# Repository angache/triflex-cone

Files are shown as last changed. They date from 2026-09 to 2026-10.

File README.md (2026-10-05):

# TriFlex

**Triple-Helix Mesh Trigger Cone**

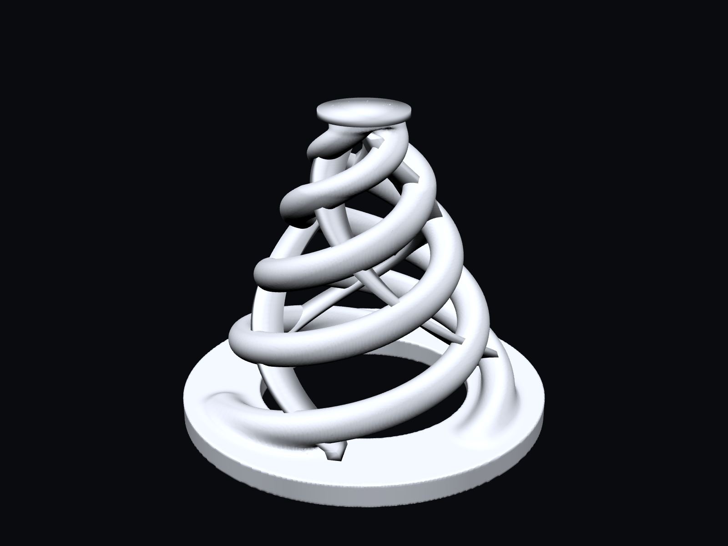
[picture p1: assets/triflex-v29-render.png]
TriFlex V29 render


**TriFlex — A 3D-printable triple-helix piezo trigger cone for electronic mesh drum pads.**

TriFlex is a mechanical trigger-cone project for electronic drums using mesh heads and piezo sensors. Instead of a conventional solid foam cone, it uses three TPU helical spring arms and stabilizing membranes to tune compliance, lateral stability, sensitivity, and hotspot behavior.

## Mechanical concept

The helix arms provide vertical compliance. The membranes add lateral stability and tune the spring response without turning the geometry into a closed shell.

The piezo is approximately 27-28 mm in diameter. A small centered adhesive pad supports its metal side against the drum plate, and TriFlex contacts the ceramic side. The piezo is therefore supported near its center from below and loaded through an annular/peripheral region from above. The center-open underside is intentional: it permits piezo flexure and is believed to contribute strongly to sensitivity. This is a mechanical hypothesis consistent with observed behavior; it has not yet been instrumented. See [docs/DESIGN.md](docs/DESIGN.md).

## Project status

**Current stable physical baseline: V30**

- TPU body height: 32 mm
- Base: Ø38 mm
- Top contact: Ø9 mm
- Three helix arms: Ø3.1 mm
- Membrane: 1.30 mm
- Membrane roots connected to base
- Center-open underside
- 3 mm allowance for a compliant top interface

V30 preserves the V29 geometry and reduces only the helix-arm diameter from Ø3.3 mm to Ø3.1 mm. Its initial test in a 12-inch PD-128 BC with an original two-ply mesh head and a TD-9 module showed excellent sensitivity and ghost-note response, substantially reduced hotspot, and good print quality. Multiple V30 prints then behaved consistently and passed strike testing of up to approximately 10,000 hits, after which V30 was promoted to stable. See [docs/TESTING.md](docs/TESTING.md).

**Previous stable control: V29**

V29 (helix Ø3.3 mm) is preserved unchanged as the previous stable reference. It produced excellent sensitivity with a substantial reduction in hotspot compared with the earlier V26 configuration.

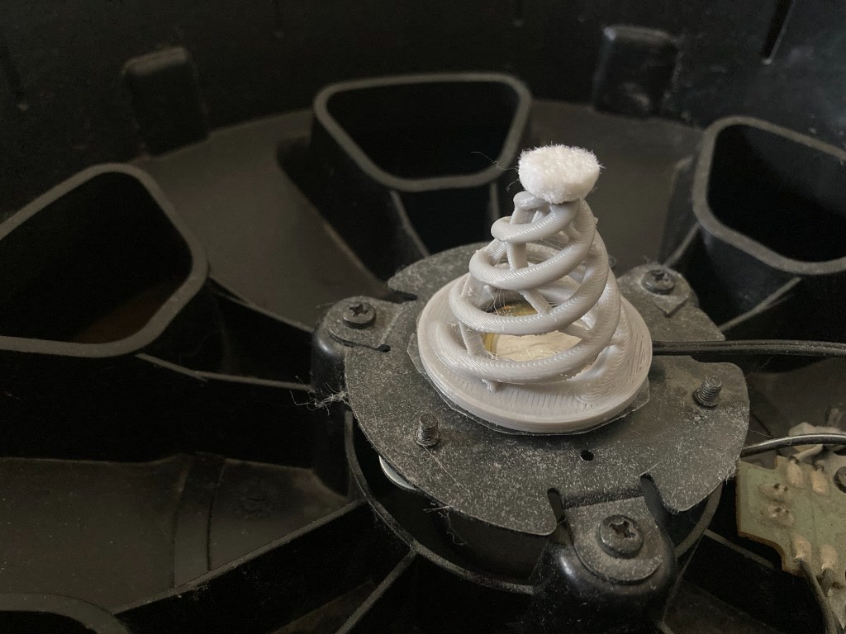
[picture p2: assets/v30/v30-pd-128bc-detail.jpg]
Physically printed V30 installed in a PD-128 BC


[View the complete V30 physical photo log](docs/V30-PHOTO-LOG.md).

### V30 physical test video

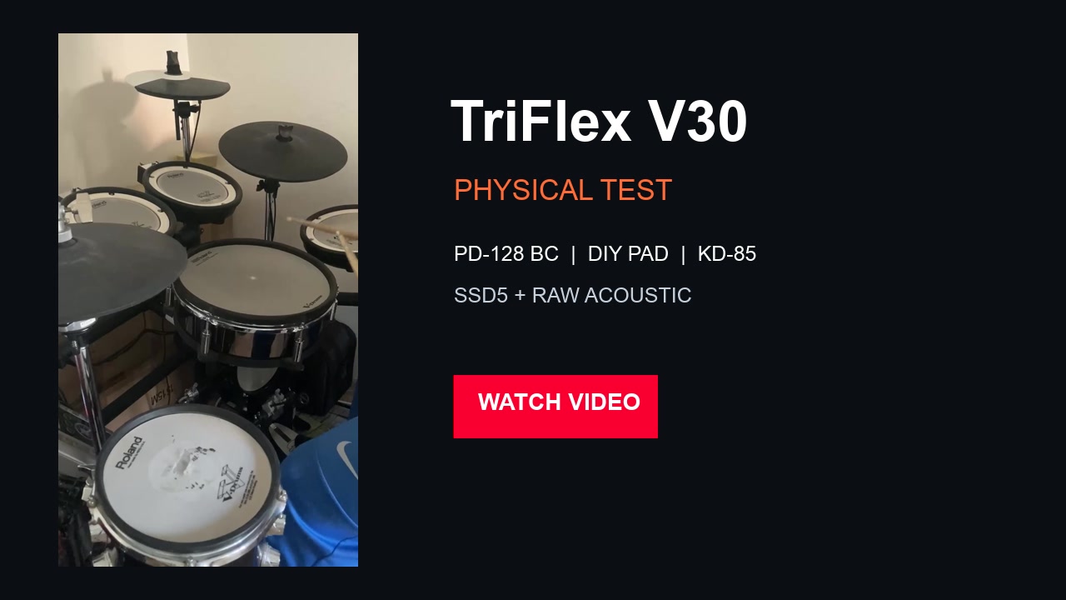
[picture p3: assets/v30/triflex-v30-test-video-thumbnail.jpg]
Watch the TriFlex V30 physical test — PD-128 BC, DIY pad, and KD-85 (https://www.youtube.com/watch?v=LNGkQPw1kC0)


Click the image to watch the PD-128 BC, DIY pad, and KD-85 test with SSD5 and raw acoustic audio.

## Model files

| File | Status |
|---|---|
| [`models/stable/triflex-v30.stl`](models/stable/triflex-v30.stl) | **Stable** — current baseline; repeatability and ~10,000-hit durability test passed |
| [`models/stable/triflex-v29.stl`](models/stable/triflex-v29.stl) | Previous stable — preserved control |

The STL files contain the 32 mm TPU body only. The 3 mm top allowance is reserved for a separate felt/foam/compliant contact and is not modeled in the STL.

Mesh check (both files): watertight, consistent winding, bounding box 38 × 38 × 32 mm, top contact Ø9.0 mm.

**Both stable STLs are preserved byte-for-byte** — V30 SHA-256 `1380294200b95626e5e04df2e983cc174459755fc91b3e286d876464239f929f`, V29 SHA-256 `6ba6824379025cc35e50dc8483c4deec778fa85bb63e8777b1d8f94238a3a9a2`. Each contains 5 closed shells/components that are not boolean-unioned. This is intentional: these exact STLs were printed and physically tested. "Non-unioned" is not permission to repair, union, remesh, or normalize a stable file. A unioned or cleaned-up variant must be a new experimental revision and must be physically retested before it can be called stable.

## Printing and material summary

- Material: RhinoLab TPU 95A HS
- Printer: Creality Ender-3 S1, Sprite direct drive, 0.4 mm nozzle
- Slicer: Cura 5.2.1
- Layer height 0.20 mm · nozzle 220°C (first layer 225°C) · bed 35°C (first layer 40°C)
- Print speed 28 mm/s · outer wall 22 mm/s · retraction 0.5 mm at 15 mm/s · fan 20-35% after first layer
- Build plate adhesion: none — the validated V29 print used no brim
- Dry TPU before critical prints; the reference spool was dried at 70°C for approximately 8 hours.

Reference Cura profile: [`cura/TriFlex_Ender3S1_TPU95A_V29_Validated.curaprofile`](cura/TriFlex_Ender3S1_TPU95A_V29_Validated.curaprofile), extracted from the validated V29 G-code. [docs/PRINTING.md](docs/PRINTING.md) is the authoritative printing reference.

## Documentation

- [Development history — prototype evolution through V30](docs/DEVELOPMENT-HISTORY.md)
- [V30 physical photo log](docs/V30-PHOTO-LOG.md)
- [Design and geometry](docs/DESIGN.md)
- [Printing guide](docs/PRINTING.md)
- [Physical testing log](docs/TESTING.md)
- [Engineering instructions](AGENTS.md)
- [Changelog](CHANGELOG.md)

## Development discipline

TriFlex revisions should normally change one mechanical variable at a time. Generated geometry and engineering hypotheses must be distinguished from physically tested results. V30 remains unchanged as the stable reference while new experimental revisions are evaluated.

## License

TriFlex is licensed under the **Creative Commons Attribution-NonCommercial-ShareAlike 4.0 International License (CC BY-NC-SA 4.0)**.

You may share and adapt the project for non-commercial purposes with attribution. Modified versions must be identified and shared under the same or a compatible license.

Read [LICENSE.md](LICENSE.md) before downloading, modifying, printing, or redistributing the project. Commercial manufacture, sale, inclusion in paid kits/products, or other commercial exploitation requires separate written permission from Ali Tuna; see [COMMERCIAL-LICENSE.md](COMMERCIAL-LICENSE.md).

Because commercial use is restricted, this project is not described as OSI open source.

## Independence / trademarks

TriFlex is an independent project. Any third-party manufacturer or product names used in technical compatibility notes are descriptive only and do not imply affiliation, sponsorship, or endorsement.

## Development state

The repository is under active engineering development. V30 has passed print-to-print repeatability and strike testing of up to approximately 10,000 hits; longer durability runs with itemized inspection are planned.

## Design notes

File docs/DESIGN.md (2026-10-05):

# TriFlex Design

## Purpose
TriFlex replaces the conventional foam trigger cone used between a mesh drum head and a piezoelectric sensor. Its mechanical structure uses three helical TPU spring arms plus thin stabilizing membranes.

## Current stable geometry — V30
| Parameter | Value |
|---|---:|
| Body height | 32 mm |
| Base diameter | 38 mm |
| Top contact diameter | 9 mm |
| Helix arms | 3 |
| Helix phase | 120° |
| Helix arm diameter | 3.1 mm (V29: 3.3 mm) |
| Membrane thickness | 1.30 mm |
| Top compliance allowance | 3 mm |
| Underside | Center-open |

The membrane roots are connected to the base plate.

## Mechanical concept
The helix arms provide vertical compliance. The membranes add lateral stability and tune the spring response without turning the geometry into a closed shell.

The center-open underside is intentional. In the current sensor architecture the piezo is supported near its center from below while TriFlex transfers force through an annular/peripheral region from above. This permits piezo flexure and is believed to contribute strongly to sensitivity.

That explanation is a mechanical hypothesis consistent with the observed behavior; it has not yet been instrumented with force/displacement or piezo strain measurements.

## Development history
Early solid-cone concepts were too stiff. Bare helix concepts were too soft and laterally unstable. Adding membranes improved stability. V26 (35 mm height, 9 mm top, 3.3 mm helix, 1.50 mm membrane) achieved excellent sensitivity but had a strong hotspot.

V29 changed the body to 32 mm with a 3 mm compliant-tip allowance, used a 1.30 mm membrane, and connected membrane roots to the base. Physical testing showed excellent sensitivity with a substantial hotspot reduction.

Because multiple parameters changed between earlier prototypes and V29, the hotspot improvement must not be attributed to membrane thickness alone.

## V30 — current stable revision
V30 keeps the V29 geometry except for helix arm diameter:
- V29: 3.3 mm
- V30: 3.1 mm

The goal is to reduce vertical spring stiffness while retaining the 1.30 mm membranes and lateral stability.

V30's initial functional test in a 12-inch pad showed excellent sensitivity and ghost-note response, substantially reduced hotspot, and good print quality. Multiple V30 prints subsequently behaved consistently and passed strike testing of up to approximately 10,000 hits, and V30 was promoted to stable on 2026-10-05. A controlled V29/V30 A/B comparison has not been recorded; V29 is preserved unchanged as the previous stable control.

## Trademark note
TriFlex is an independent project. Compatibility with particular electronic-drum systems may be documented descriptively, but manufacturer names and trademarks are not part of the TriFlex brand.

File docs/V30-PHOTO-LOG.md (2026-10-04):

# V30 Physical Photo Log

These photographs document the physically printed V30 prototype, installation examples, the compliant felt interface, and comparison with conventional foam cones.

V30 is physically printed and has completed an initial successful functional test. The photographs are evidence of physical construction and installation; they do not by themselves establish durability or production readiness.

Third-party manufacturer and product names are used descriptively only. TriFlex is independent and is not affiliated with, sponsored by, or endorsed by those manufacturers.

## PD-128 BC installation

V30 installed in a PD-128 BC pad with the compliant felt interface.

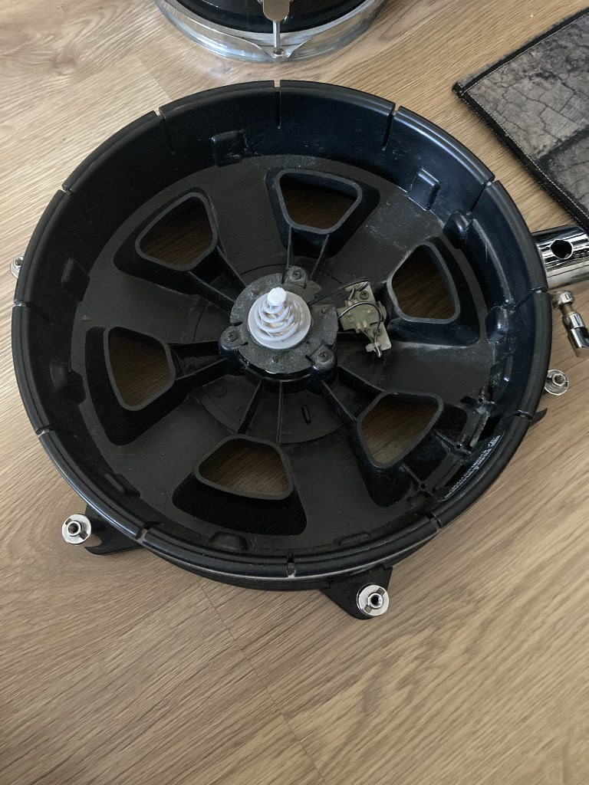
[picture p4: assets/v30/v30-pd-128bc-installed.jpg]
V30 installed in PD-128 BC


V30 in PD-128 BC — detail

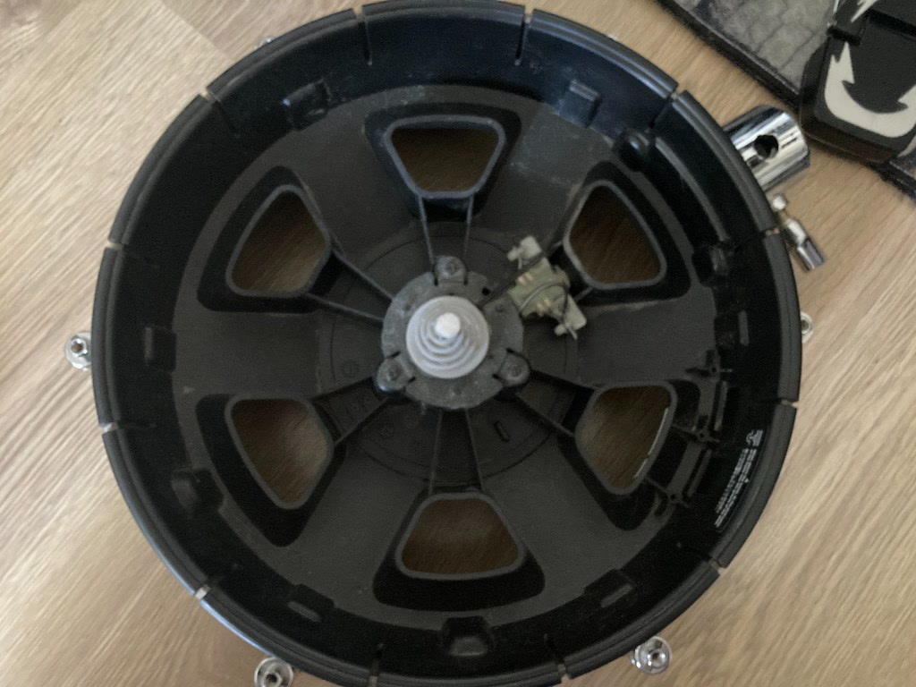
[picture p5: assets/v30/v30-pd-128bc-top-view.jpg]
V30 in PD-128 BC — top view


## KD-85 installation

KD-85 kick-pad assembly and the installed V30 prototype.

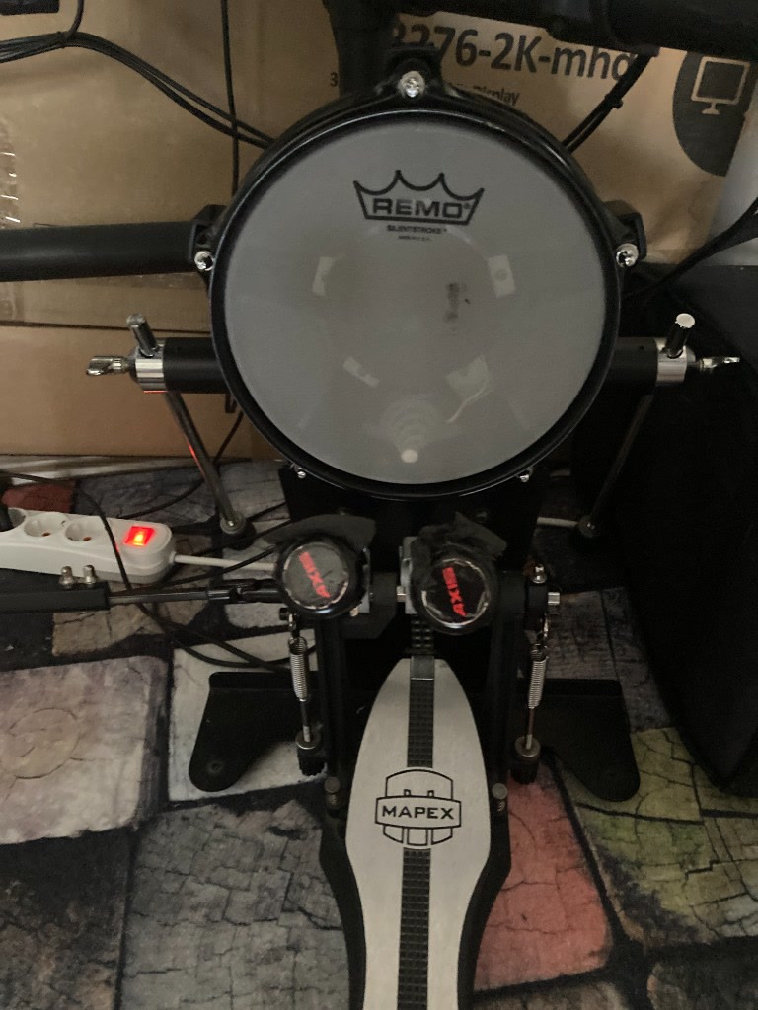
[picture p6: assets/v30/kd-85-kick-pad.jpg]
KD-85 kick pad


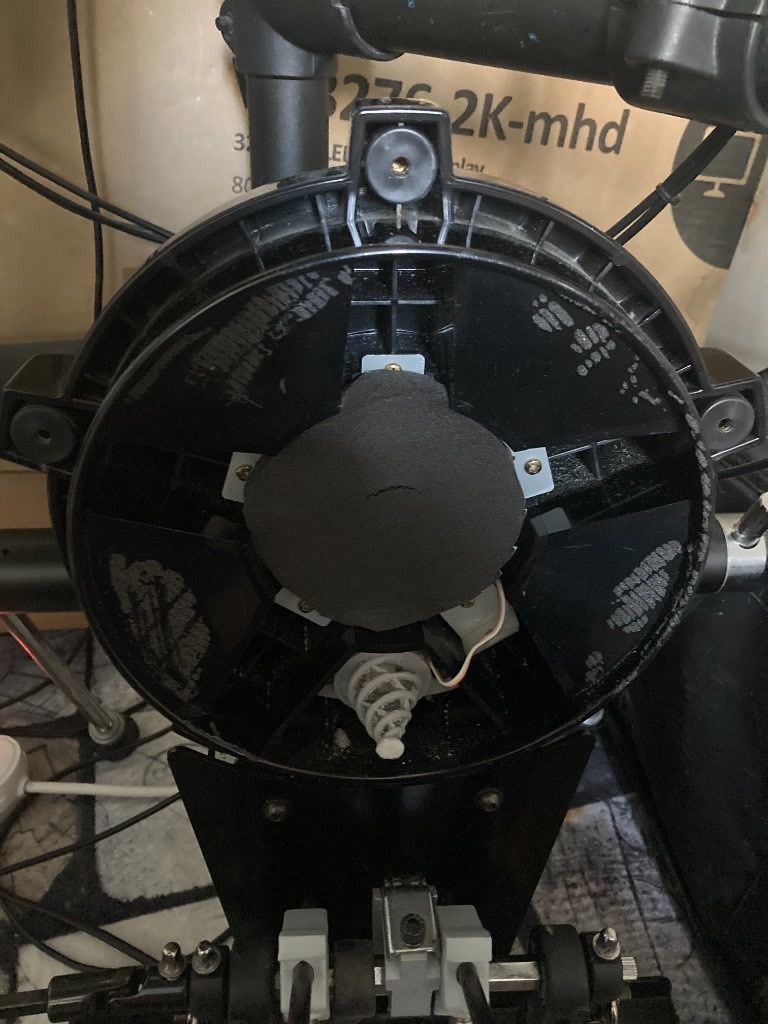
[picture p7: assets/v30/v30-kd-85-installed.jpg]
V30 installed in KD-85


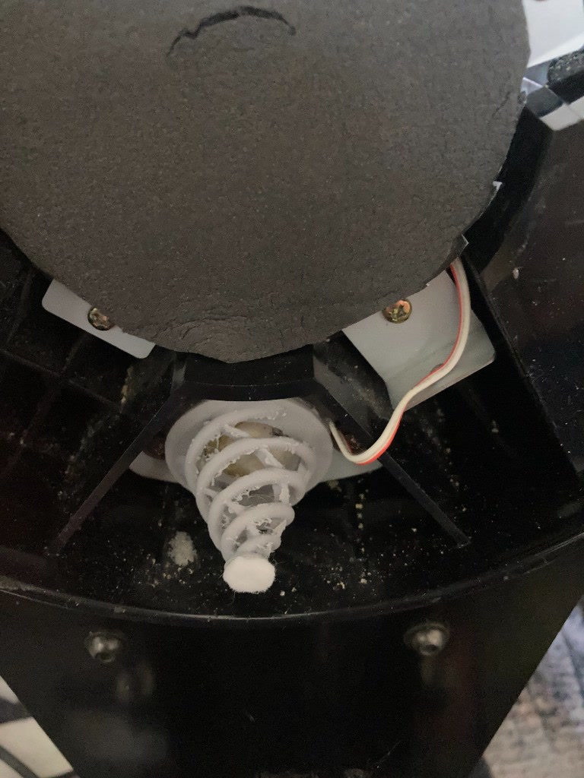
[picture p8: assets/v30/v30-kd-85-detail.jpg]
V30 in KD-85 — detail


## DIY pad installation

V30 installed in a custom DIY pad assembly.

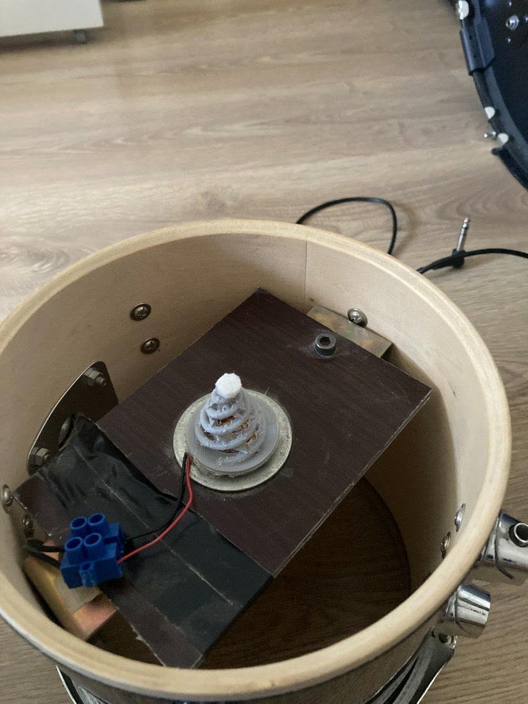
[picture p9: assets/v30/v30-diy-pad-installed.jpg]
V30 installed in a DIY pad


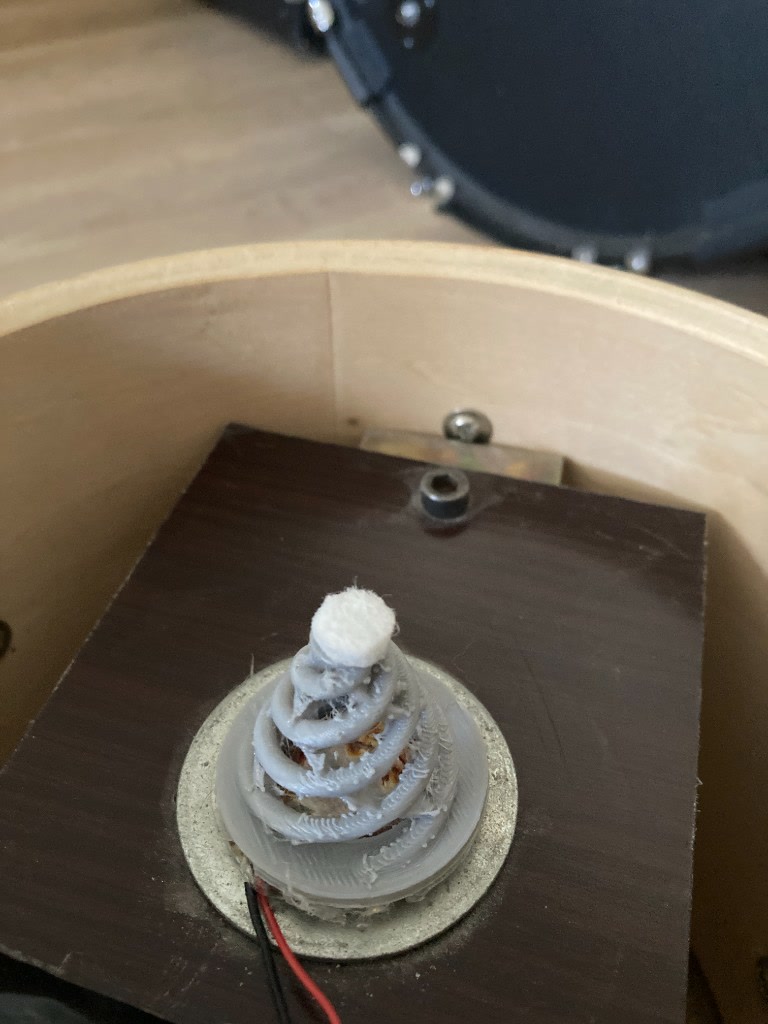
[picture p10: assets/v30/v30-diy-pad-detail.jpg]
V30 in a DIY pad — detail


## Compliant felt interface

Self-adhesive furniture felt discs used as the compliant top interface. These are ordinary furniture-protection pads that can be sourced from furniture or household-goods stores.

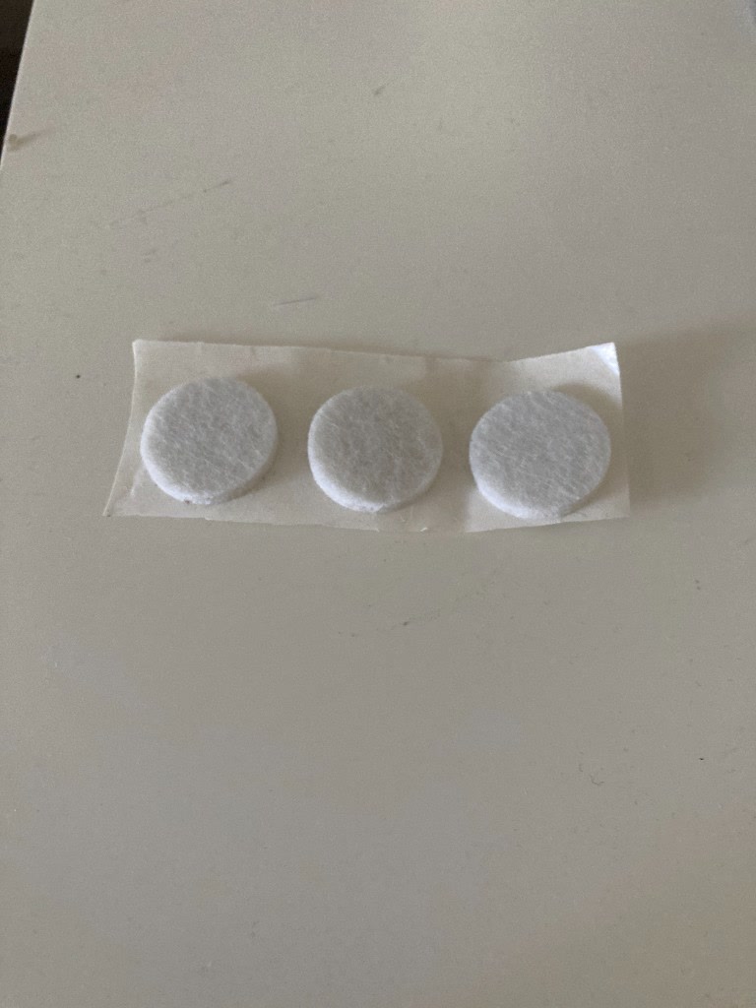
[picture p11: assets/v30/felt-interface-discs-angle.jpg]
Felt interface discs — angled view


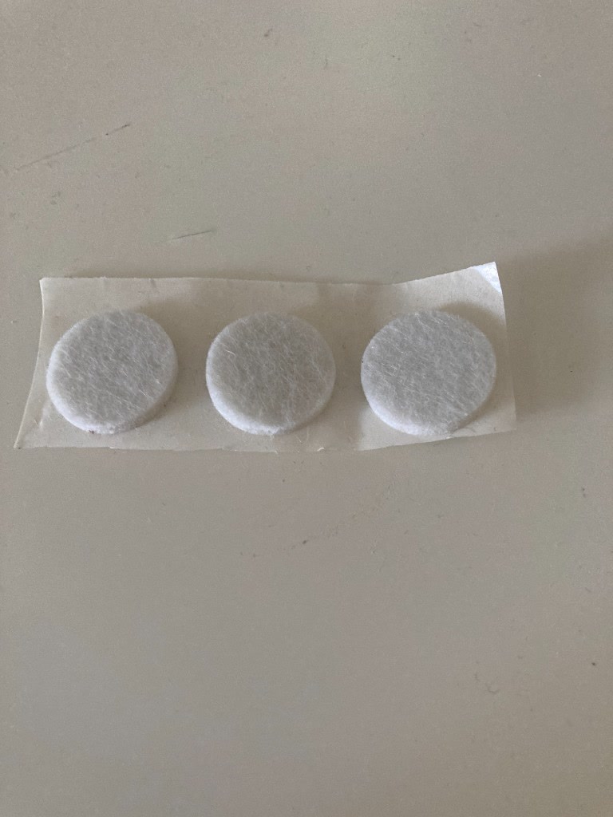
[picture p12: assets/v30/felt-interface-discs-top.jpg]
Felt interface discs — top view


## Conventional cone comparison

The damaged original cone removed from the PD-128 BC and a visual comparison between a used/damaged original cone and an unused original cone.

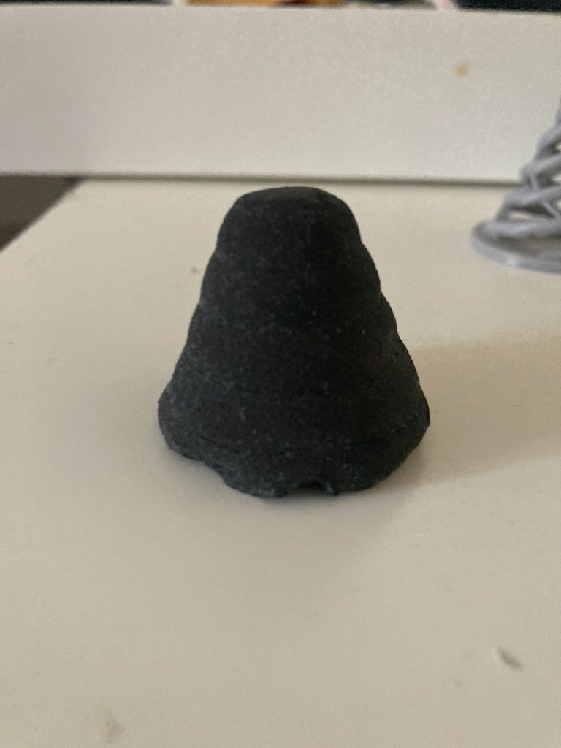
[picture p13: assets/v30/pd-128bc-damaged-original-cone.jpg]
Damaged original PD-128 BC cone


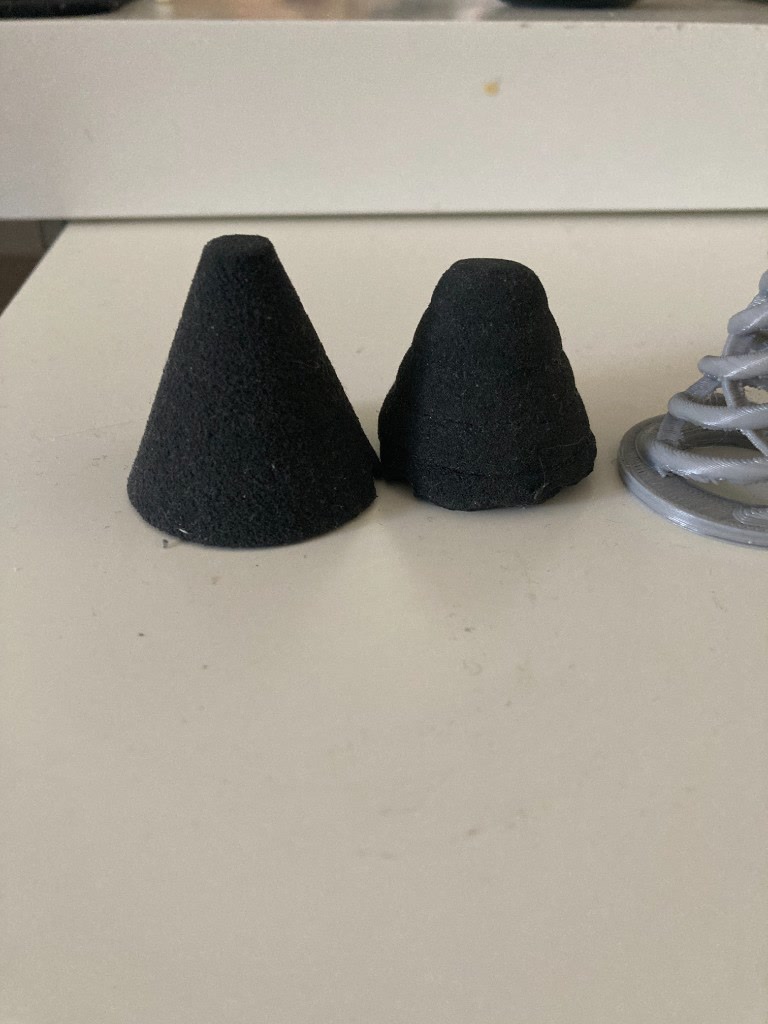
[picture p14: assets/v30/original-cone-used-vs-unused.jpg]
Used and unused original cones


## Physical test video

[Watch the V30 test on PD-128 BC, DIY pad, and KD-85 — SSD5 + raw acoustic audio](https://www.youtube.com/watch?v=LNGkQPw1kC0).

The first half uses Steven Slate Drums 5 triggered through TD-9 MIDI. The second half repeats the same performance with the raw physical pad sound recorded by the camera microphone.

## Publication note

The published JPEG files were re-encoded without source EXIF metadata. The original photographs are retained locally outside version control.

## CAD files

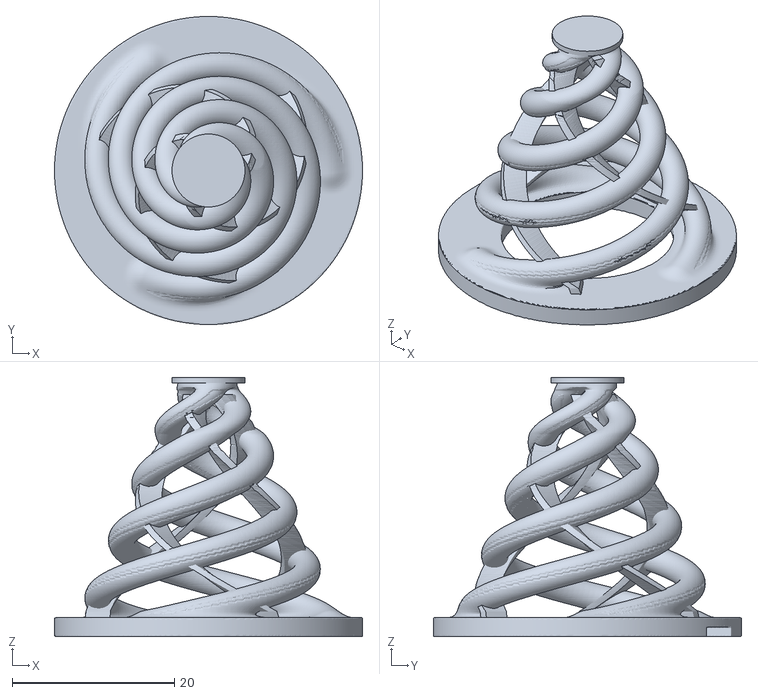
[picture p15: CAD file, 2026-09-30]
models/stable/triflex-v30.stl
38.0 x 38.0 x 32.0

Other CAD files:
models/stable/triflex-v29.stl

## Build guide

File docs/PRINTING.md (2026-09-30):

# TriFlex Printing Guide

## Reference setup
- Printer: Creality Ender-3 S1
- Extruder: Sprite direct drive
- Nozzle: 0.4 mm
- Material: RhinoLab TPU 95A HS
- Slicer reference: Cura 5.2.1

## Current reference profile
Reference Cura profile: `cura/TriFlex_Ender3S1_TPU95A_V29_Validated.curaprofile`.

| Setting | Value |
|---|---:|
| Layer height | 0.20 mm |
| First layer | 0.20 mm |
| Nozzle | 220°C |
| First-layer nozzle | 225°C |
| Bed | 35°C |
| First-layer bed | 40°C |
| Flow | 100% |
| Print speed | 28 mm/s |
| Wall speed | 25 mm/s |
| Outer wall | 22 mm/s |
| Top/bottom | 22 mm/s |
| Travel | 180 mm/s |
| Retraction | 0.5 mm |
| Retraction speed | 15 mm/s |
| Fan | 20-35% after first layer |
| Minimum layer time | 10 s |
| Build plate adhesion | None (`adhesion_type = none`) — no brim |
| Supports | Disabled |

Retraction prime speed: 15 mm/s. Z-hop is off. Combing is set to infill and avoid-other-parts is enabled.

## Validated V29 print
The physically validated V29 test print was sliced in Cura 5.2.1 (machine definition `creality_ender3s1`) with:
- `adhesion_type = none`
- therefore **no brim** was used.

The profile also stores `brim_width = 6`. That value is inactive when `adhesion_type = none` and is not part of the validated V29 setup.

G-code summary of the validated print: max Z 32 mm, estimated print time 3934 s (~66 min), 1.40 m of filament.

The validated G-code is archived outside this repository (SHA-256 `76a47994a570abb57471f831934960b78eb8f7002983c95e7bb85267b698f32d`).

The reference profile `cura/TriFlex_Ender3S1_TPU95A_V29_Validated.curaprofile` was extracted from the settings embedded in that G-code. Only the profile display name was changed; all slicing values are identical to the validated print.

`cura/legacy/Ender3_S1_RhinoLab_TPU95A_HS_V28_SAFE_V24.curaprofile` is the original hand-kept profile, preserved as a source artifact. It is **not** the V29 reference: it sets `adhesion_type = brim` and targets `creality_base`, so importing it as-is would print a brim.

## Brim (optional troubleshooting aid)
A 6 mm brim may be enabled if first-layer adhesion fails or corners lift. It is an adhesion aid only, not the validated V29 default. A print made with a brim deviates from the validated setup and should be noted as such in docs/TESTING.md.

## TPU moisture
TPU moisture strongly affects stringing. The current material produced nearly string-free tower tests after drying at 70°C for approximately 8 hours.

For repeatability:
- dry before critical prints;
- print directly from a filament dryer when practical;
- keep the spool enclosed;
- use a separate room hygrometer rather than treating the dryer's internal RH display as room humidity.

A cautious starting dryer temperature while actively printing is approximately 50-55°C, subject to spool/dryer/material manufacturer limits.

## Supports
The baseline model is intended to minimize support dependency. If support is required, a conservative TPU starting point is:
- Tree support
- Build plate only
- ~55° overhang threshold
- Zig Zag
- 5-8% density
- 0.30 mm Z distance
- ~0.6 mm X/Y distance
- interface enabled, 0.20-0.40 mm thick, 20-25% density

Avoid dense Grid support for this geometry.

## Bed removal
Let the plate cool before removal. Flex the magnetic sheet and avoid pulling the part by its helix arms. If adhesion is excessive, check first-layer squish and consider raising Z offset about 0.05 mm after calibration.

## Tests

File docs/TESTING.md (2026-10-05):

# TriFlex Test Log

This file separates physical observations from engineering hypotheses.

## V26 — physical test
Geometry:
- H35
- base Ø38
- top Ø9
- helix Ø3.3
- membrane 1.50 mm
- center-open underside

Observed:
- Excellent sensitivity.
- Tested successfully on 8-inch and 12-inch mesh pads.
- Strong hotspot directly over the cone.

Conclusion:
V26 established that the triple-helix/membrane architecture can achieve very high sensitivity, but hotspot control required further development.

## V29 — physical test / previous stable baseline (preserved control)
Geometry:
- H32
- base Ø38
- top Ø9
- helix Ø3.3
- membrane 1.30 mm
- membrane roots connected to base
- center-open underside
- 3 mm top allowance

Print record:
- STL: `models/stable/triflex-v29.stl` (5 closed, non-unioned shells)
- Sliced in Cura 5.2.1 with `cura/TriFlex_Ender3S1_TPU95A_V29_Validated.curaprofile` settings
- Build plate adhesion: none (no brim)
- G-code archived outside the repository (SHA-256 `76a47994a570abb57471f831934960b78eb8f7002983c95e7bb85267b698f32d`)

Observed:
- Excellent overall response.
- Hotspot substantially lower than the previous configuration.
- User assessment: best-performing cone tested in the project so far.

Important:
Several mechanical variables differ from V26, so the hotspot reduction cannot yet be assigned to one variable.

## V30 — current stable baseline
Geometry:
- Same as V29
- helix Ø3.1 instead of Ø3.3
- membrane remains 1.30 mm

Hypothesis:
Reducing arm diameter should soften the vertical spring response while preserving membrane-controlled lateral stability. A simple beam-style d^4 comparison suggests 3.1 mm arms have roughly 78% of the bending stiffness of 3.3 mm arms, but the actual TriFlex geometry is not a simple beam. This remains a design-direction estimate, not a measured complete-cone stiffness result.

### Initial physical test
Setup:
- Pad: 12-inch PD-128 BC
- Mesh head: original two-ply Roland mesh
- Module: Roland TD-9
- Top interface: self-adhesive furniture felt
- Module trigger settings: not yet recorded
- Test duration: not yet recorded

Observed (subjective user assessment):
- Excellent sensitivity.
- Excellent ghost-note response.
- Hotspot was substantially reduced.
- Print quality was good.

Not yet recorded:
- Controlled V29/V30 A/B comparison.
- Lateral-stability assessment.
- Print-to-print repeatability.
- Extended durability or cyclic-hit result.

Status at the time of the initial test:
- Initial physical test successful.
- V30 remained experimental pending repeatability and durability work.

Photographs: [V30 physical photo log](V30-PHOTO-LOG.md).

### Video demonstration

[Watch the V30 test on YouTube](https://www.youtube.com/watch?v=LNGkQPw1kC0).

The same performance is shown twice:
- 00:00 — Steven Slate Drums 5 (SSD5), triggered through TD-9 MIDI
- 00:58 — raw physical pad sound recorded by the camera microphone

Performance order:
1. 12-inch PD-128 BC
2. Custom DIY mesh pad
3. KD-85 kick pad

The original combined video is archived outside version control (SHA-256 `c93ed8d2d40ef7bc48ab52c7d52ae94c099c6ef5cd59a30ca403bda171156ca6`).

### Repeatability and durability test — 2026-10-05
Reported by the maintainer:
- Repeatability: multiple V30 prints were tested and behaved consistently.
- Durability: strike testing of up to approximately 10,000 hits.
- Result: passed.

Not separately recorded:
- Exact hit count per print, pads and module settings used during the durability run.
- Itemized post-test inspection (membrane-root cracking, helix fatigue, permanent set, top deformation).
- Before/after response comparison.

Decision:
- V30 promoted to the stable baseline.
- STL moved to `models/stable/triflex-v30.stl`, byte-for-byte identical to the tested file (SHA-256 `1380294200b95626e5e04df2e983cc174459755fc91b3e286d876464239f929f`). Like V29, it contains 5 closed, non-unioned shells; bounding box 38 × 38 × 32 mm.
- V29 is preserved unchanged as the previous stable control.

## Planned durability work
Extended strike testing beyond 10,000 hits (for example 20,000 hits) with itemized inspection for membrane-root cracking, helix fatigue, permanent set, top deformation, and response drift.

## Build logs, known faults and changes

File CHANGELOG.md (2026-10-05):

# Changelog

## 2026-10-05 — V30 promoted to stable
### Changed
- V30 promoted to the stable baseline after multiple prints behaved consistently and passed strike testing of up to approximately 10,000 hits.
- `models/experimental/triflex-v30-experimental.stl` moved to `models/stable/triflex-v30.stl` without modification (SHA-256 `1380294200b95626e5e04df2e983cc174459755fc91b3e286d876464239f929f`).
- V29 retained unchanged as the previous stable control.
- README, AGENTS.md, docs/DESIGN.md, docs/TESTING.md and docs/DEVELOPMENT-HISTORY.md updated for the new baseline.

## Unreleased
### Added
- Initial TriFlex repository structure.
- Engineering baseline documentation.
- Printing reference profile documentation.
- Physical test log.
- Repository engineering instructions.
- `models/stable/triflex-v29.stl` — the physically validated V29 STL, preserved byte-for-byte (5 closed, non-unioned shells).
- `models/experimental/triflex-v30-experimental.stl` — physically tested experimental V30 STL; repeatability and durability pending.
- `cura/TriFlex_Ender3S1_TPU95A_V29_Validated.curaprofile` — reference profile extracted from the validated V29 G-code; only the display name changed.
- `cura/legacy/Ender3_S1_RhinoLab_TPU95A_HS_V28_SAFE_V24.curaprofile` — original profile kept as a source artifact (not the V29 reference).
- V30 physical photo set covering PD-128 BC, KD-85, and DIY-pad installations, the felt interface, and original-cone comparisons.
- `docs/V30-PHOTO-LOG.md` — captions and context for the physical photo set.
- Public V30 test video demonstrating PD-128 BC, DIY pad, and KD-85 with SSD5 and raw acoustic audio.

### Changed
- docs/PRINTING.md: validated V29 print used `adhesion_type = none` (no brim); 6 mm brim is documented only as an optional adhesion aid.
- Replaced the custom personal/non-commercial license with the standardized CC BY-NC-SA 4.0 license; copyright holder recorded as Ali Tuna.

### Stable reference
- V30: V29 baseline with helix diameter reduced from Ø3.3 to Ø3.1 mm. Repeatability and ~10,000-hit durability test passed.
- V29 (previous stable control): H32 / base Ø38 / top Ø9 / helix Ø3.3 / membrane 1.30 mm / base-connected membranes / center-open underside / 3 mm compliant-tip allowance.

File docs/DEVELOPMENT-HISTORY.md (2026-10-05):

# TriFlex Development Report — Prototype Evolution to V30

This document records the engineering path that led to the current TriFlex triple-helix mesh trigger cone. It preserves successful dimensions, failed approaches, physical observations, corrections, and the development discipline used to reach the current design.

Sections describing work before V26 are retrospective development notes. Where no dated artifact or formal test record exists in the repository, they should not be interpreted as instrumented laboratory data.

## 1. Development objective

The project began with a practical target: replace the conventional foam cone used between a mesh drum head and a piezo sensor with a 3D-printable TPU structure that is sensitive enough for ghost notes, mechanically stable under the mesh head, compliant vertically, resistant to excessive lateral wobble, capable of allowing the piezo to flex rather than simply compressing it, reproducible with FDM printing, and less prone to a strong center hotspot.

The reference envelope evolved around a roughly Ø38 mm base and an installed height of approximately 35 mm.

The current sensor architecture uses an approximately Ø27–28 mm piezo. A small centered adhesive pad supports the metal side of the piezo against the drum plate. TriFlex contacts the ceramic side. The underside remains center-open so the piezo can flex under annular/peripheral loading.

Prototypes using this center-open load path have shown very high sensitivity in physical testing. The load path is therefore intentionally preserved, but its causal contribution and exact strain distribution have not yet been instrumented; the explanation remains an engineering hypothesis rather than a measured result.

## 2. Development strategy

The project gradually moved from exploratory geometry toward controlled A/B development.

Current rules:

1. Preserve a physically successful revision as a reference artifact.
2. Change one mechanical variable at a time whenever practical.
3. Separate physical observations from mechanical hypotheses.
4. Do not call an STL stable merely because it is watertight or slices successfully.
5. Do not repair, remesh, smooth, or boolean-union a validated STL merely for CAD cleanliness.
6. Keep the center-open piezo load path unless a dedicated experiment is intended to test it.
7. Treat the compliant top interface as part of the mechanical system.
8. Validate generated files for dimensions, mesh integrity and slicing before printing.
9. A new revision becomes stable only after completing the required physical test scope; an initial successful test alone does not make it stable.

This discipline was adopted after early prototypes changed too many geometric variables at once, making it difficult to identify the cause of improvements.

## 3. Prototype evolution

### Solid cone — rejected

The first basic direction was a solid TPU cone.

**Physical result:** too stiff.

The solid structure did not provide the spring behavior required for a responsive mesh-head trigger.

**Lesson:** compliance had to come from geometry rather than Shore hardness alone.

### Bellows concepts — promising compliance, poor print behavior

Several bellows-style cones were developed. The bellows geometry provided substantially more vertical movement than the solid cone and demonstrated that a structured TPU spring could work.

Problems included stringing, weak or separated bellows roots, local tearing, difficult support removal, and excessive stiffness in later reinforced variants.

A bellows + membrane hybrid was one of the better intermediate concepts and confirmed that thin membranes could stabilize an otherwise compliant structure.

**Lesson:** the structure needed a cleaner load path and fewer print-sensitive folds.

### Double-helix concepts — too soft / unstable

A double-helix spring was explored. It provided excellent freedom of movement but became too soft and laterally unstable for the intended mesh-head application.

Attempts included smoother top/bottom transitions, fillets, channels and membrane-assisted variants.

**Lesson:** helix springs were promising, but two arms did not provide enough lateral control.

### Lattice / trellis / matrix concepts — rejected for manufacturability

Internal lattice and mesh-like structures introduced substantial manufacturing problems: difficult slicing, inaccessible support material, poor support removal in TPU, and unnecessary internal complexity.

**Lesson:** an open, printable spring structure was preferable to an internal lattice.

### Triple helix — architecture selected

The design converged on three independent helical spring arms spaced approximately 120° apart. The third arm improved lateral stability while retaining vertical compliance.

The architecture became three rounded TPU helix arms, open spaces between the arms, a small flat top contact, a wide circular base, and later thin membranes associated with the helix arms.

This triple-helix architecture became the foundation of TriFlex.

## 4. Membrane development

The bare triple helix was still too soft and could wobble laterally.

Thin membranes were added along the inner/back side of the helix arms. Their purpose was not to turn the cone into a closed shell, but to stabilize the spring system and tune its response.

Design principle:

> Helix arms primarily provide vertical compliance; membranes primarily provide lateral stability and additional spring tuning.

Membrane geometry therefore became a separate design variable from helix diameter.

## 5. V26 — first major physical success

V26 was the first prototype that demonstrated the core architecture could outperform the earlier concepts.

### Geometry

- Body height: 35 mm
- Base: Ø38 mm
- Top contact: Ø9 mm
- Helix arms: 3
- Helix diameter: Ø3.3 mm
- Membrane: 1.50 mm
- Underside: center-open

### Physical testing

V26 was tested in both 8-inch and 12-inch mesh pads.

Observed:
- excellent sensitivity,
- very good low-level triggering,
- strong overall response,
- but a pronounced hotspot directly above the cone.

The subjective assessment was that the basic cone behavior was exceptionally good apart from the hotspot.

### Engineering interpretation

The same architecture that produces strong sensitivity probably also concentrates the direct center strike. The center-supported piezo and peripheral/annular loading allow strong piezo bending.

The project deliberately did not respond by immediately filling the center or drastically reducing electronic sensitivity, because either change could sacrifice ghost-note performance.

V26 established the triple-helix + membrane + center-open architecture as the direction to continue.

## 6. Mesh and geometry correction attempts

Several intermediate STL operations were attempted while trying to improve membrane surfaces and installed height.

A visible stair-step/ladder appearance existed on the membranes in Cura while the helix arms appeared comparatively smooth.

Findings:
- the defect was already present in the source geometry,
- generic mesh smoothing was not an appropriate correction,
- the STL was watertight, so searching only for open boundary chains did not address the problem,
- global smoothing risked changing helix diameter and membrane thickness,
- and a file should not be labelled "smooth" unless the geometry has actually changed and been visually/mesh validated.

A global Z-scaling approach during the V27 stage also demonstrated why uncontrolled transforms are undesirable: they can preserve unwanted membrane artifacts while changing mechanical dimensions elsewhere.

**Lesson:** future cleanup should reconstruct the intended smooth helical membrane parametrically rather than applying generic mesh smoothing to the complete validated part.

## 7. Installed height and compliant top interface

The project separated the TPU spring body from the final mesh-contact layer.

A 3 mm self-adhesive furniture felt was available and proved mechanically attractive as the top interface.

The target became:
- TPU body: 32 mm
- compliant top interface: approximately 3 mm
- installed system height: approximately 35 mm

The felt is cut to approximately Ø9–10 mm to match the contact region.

It is treated as a functional mechanical layer because it can soften the initial mesh-to-TPU impact, provide a short compliant transition, distribute the first stage of contact, reduce hard direct contact, and potentially contribute to hotspot control.

The felt should be held constant during geometry A/B tests.

Alternative progressive TPU tips with multiple small rounded contact points were considered, but felt and printed-tip concepts should be tested separately rather than stacked together.

## 8. V28 — 32 mm body / tip allowance stage

V28 established the 32 mm TPU-body target with 3 mm reserved for the compliant top interface.

The lower geometry was largely preserved while the upper region was compressed to achieve the new height.

A structural issue was then noticed: the membrane roots did not clearly join the base plate.

This was important because membrane-to-base attachment affects lateral stability and is therefore a genuine mechanical variable, not merely a cosmetic mesh correction.

## 9. V29 — physically validated stable reference

V29 incorporated the next major mechanical refinement.

### Geometry

- Body height: 32 mm
- Base: Ø38 mm
- Top: Ø9 mm
- Three helix arms
- Helix diameter: Ø3.3 mm
- Membrane: 1.30 mm
- Membrane roots connected to base
- Center-open underside
- 3 mm compliant-top allowance

Compared with V26, several variables had changed: body height 35 → 32 mm, membrane 1.50 → 1.30 mm, membrane roots connected to the base, and a separate 3 mm top-interface allowance was introduced.

For that reason, the subsequent hotspot improvement cannot scientifically be attributed to membrane thinning alone.

### Physical result

V29 produced excellent overall sensitivity, very good response, substantially reduced hotspot, and the best overall performance observed in the project up to that test.

This made V29 the **current physically validated stable baseline**.

### Stable-artifact rule

The canonical V29 STL contains five closed, non-unioned shells/components.

Because that exact STL was successfully sliced, printed and physically tested, it is intentionally preserved as-is.

It must not be silently boolean-unioned, remeshed, normalized or "repaired." A cleaned or unioned version would be a new experimental derivative and would require physical retesting.

> Reproducibility of a physically validated artifact takes priority over cosmetic CAD cleanliness.

## 10. V30 — physically tested experimental candidate

V30 is the latest design revision.

The goal is to make the spring slightly softer without sacrificing the lateral stability obtained from the 1.30 mm membranes.

V30 preserves the V29 target geometry except for one intended mechanical variable:
- V29 helix: Ø3.3 mm
- V30 helix: Ø3.1 mm

The membrane remains 1.30 mm.

For a simplified bending member, stiffness has a strong diameter dependence. A simple comparison gives (3.1 / 3.3)^4 ≈ 0.78, suggesting roughly 22% lower arm bending stiffness in an idealized beam comparison.

TriFlex is not a simple straight beam, so this is not a prediction of 22% lower complete-cone stiffness. It is only a design-direction estimate.

V30 has been physically printed and completed an initial successful functional test.

### Initial physical test

Setup:
- 12-inch PD-128 BC pad,
- original two-ply Roland mesh head,
- Roland TD-9 module,
- self-adhesive furniture-felt top interface.

Subjective observations:
- excellent sensitivity,
- excellent ghost-note response,
- substantially reduced hotspot,
- good print quality.

Module trigger settings and test duration were not recorded. Controlled V29/V30 A/B comparison, print-to-print repeatability, and extended durability also remain outstanding. V30 is therefore a **physically tested experimental candidate**, not the stable baseline.

Physically printed V30 installed in a PD-128 BC

Additional physical installations in a KD-85 kick pad and a custom DIY pad are documented photographically without separate performance claims. See the [complete V30 physical photo log](V30-PHOTO-LOG.md).

A combined [V30 test video](https://www.youtube.com/watch?v=LNGkQPw1kC0) demonstrates the PD-128 BC, DIY pad, and KD-85 in sequence. The same performance is presented first through Steven Slate Drums 5 via TD-9 MIDI and then with the raw physical pad sound.

## 11. Material development

The current reference material is RhinoLab TPU 95A HS.

Published properties used during development include approximately:
- Shore hardness: 95A
- density: ~1.22 g/cm³
- tensile strength: ~27.3 MPa
- elongation: >650%
- recommended drying: approximately 70°C / 8 h

The material has already demonstrated excellent physical trigger behavior in the validated prototype, so it is the project benchmark rather than merely a temporary filament.

Future TPU comparisons should use the same STL and same test conditions. Geometry and material should not be changed simultaneously.

## 12. Moisture and stringing correction

TPU moisture became a major manufacturing variable.

Earlier prints showed heavy stringing and occasional weak features. After drying the RhinoLab TPU at approximately 70°C for around 8 hours, stringing tower performance became nearly clean.

Stringing returned after the spool spent time exposed to ambient air. This observation is consistent with filament conditioning materially affecting print quality, but ambient moisture uptake was not instrumented.

Current manufacturing practice:
- dry TPU before critical prints,
- print directly from the dryer when practical,
- keep the spool enclosed,
- do not infer room humidity from the dryer's internal RH reading,
- use a separate room hygrometer when environmental tracking is required.

This changed the project approach: some apparent geometry failures can actually be process/material-conditioning failures.

## 13. Printing process corrections

Reference machine:
- Creality Ender-3 S1
- Sprite direct drive
- 0.4 mm nozzle
- Cura 5.2.1

The physically validated V29 G-code established the authoritative slicing reference.

A repository audit found that the Cura profile contained a stored brim width of 6 mm, but the actual validated V29 G-code used adhesion type "none". Therefore the validated V29 print used **no brim**.

The 6 mm brim is documented only as an optional troubleshooting aid, not as the reference process.

The reference profile is named:

TriFlex_Ender3S1_TPU95A_V29_Validated.curaprofile

It was extracted from the validated G-code so the repository profile represents the actual successful print rather than relying on an older hand-maintained profile.

## 14. Support strategy

Dense support proved undesirable with TPU because it was difficult to remove and could damage delicate geometry.

The design direction therefore favors support-minimized geometry.

If support becomes necessary, the conservative starting strategy is sparse tree support, build-plate-only, with generous TPU separation and a light interface. Dense Grid support is avoided.

## 15. Sensor architecture lessons

Sensor-side decisions intentionally preserved:
- piezo approximately Ø27–28 mm,
- small centered adhesive support on the metal side,
- TriFlex contacting the ceramic side,
- center-open cone underside,
- no central post,
- outer piezo area allowed to flex.

Filling the center may reduce hotspot but could also reduce sensitivity and ghost-note response. It should not be introduced casually into the stable design.

A flexible neck directly below the top contact was also rejected because excessive local compliance there could interfere with mesh-head behavior.

## 16. What the project has learned

- A solid TPU reproduction of a foam cone is too stiff.
- Geometric compliance is more important than nominal Shore hardness alone.
- Bellows can provide compliance but are print-sensitive.
- Two helix arms are too laterally unstable.
- Three helix arms provide a better stability/compliance balance.
- Membranes are effective for controlling lateral motion.
- Membrane thickness and helix diameter should be treated as separate tuning variables.
- The center-open piezo load path appears to be a major contributor to sensitivity.
- Hotspot reduction must not be pursued at the expense of ghost-note sensitivity.
- A compliant felt contact layer is promising and should be standardized during testing.
- TPU moisture control materially affects print quality.
- Validated G-code is more authoritative than stale slicer-profile labels.
- A mechanically validated STL should not be cosmetically "fixed" without creating a new experimental revision.
- One-variable A/B testing is now the preferred development method.

## 17. Current state

### Stable physical baseline — V29

H32 / base Ø38 / top Ø9 / helix Ø3.3 / membrane 1.30 / membrane roots connected / center-open / 3 mm compliant-top allowance.

V29 remains the preserved stable control.

### Physically tested experimental candidate — V30

Same target system as V29, with helix diameter reduced from Ø3.3 to Ø3.1 mm.

V30 has been physically printed and completed an initial successful functional test. It must not be described as stable or production-ready until controlled comparison, repeatability, and durability work is recorded.

## 18. Next development step

The next controlled test should keep all practical variables fixed and compare V29 against V30.

Record at minimum:
- material and drying state,
- slicer/profile,
- felt thickness and diameter,
- pad size,
- drum module/settings,
- low-level/ghost-note response,
- center hotspot,
- edge-to-center response,
- lateral stability,
- rebound/feel,
- visible deformation,
- print defects.

V30 can be considered for promotion only if controlled comparison and repeated prints support the initial positive result without materially worsening hotspot, lateral stability, or triggering consistency. Until then, V29 remains the stable reference and V30 remains experimental.

Longer-term validation should include multiple prints and cyclic strike testing (initial milestones: 10,000 and 20,000 hits), followed by inspection for helix fatigue, membrane-root cracking, permanent set, height loss and response drift.

---

## 19. Update — V30 promoted to stable (2026-10-05)

Multiple V30 prints behaved consistently and passed strike testing of up to approximately 10,000 hits, as reported by the maintainer. V30 was promoted to the stable baseline and its STL moved, unmodified, to `models/stable/triflex-v30.stl`. The controlled V29/V30 A/B comparison described in section 18 was not recorded before promotion. V29 remains preserved as the previous stable control. Sections 17 and 18 above describe the state before this promotion.

---

**Revision note:** This report documents the development path through V30. It deliberately distinguishes measured/observed results from engineering hypotheses, preserves V29 as the stable control, and records V30 as a physically tested experimental candidate with repeatability and durability work still pending.

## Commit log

2026-09-30 Add docs/PRINTING.md
2026-09-30 Add V29/V30 model files, validated V29 Cura profile, and render
    - models/stable/triflex-v29.stl: physically validated V29 STL, byte-for-byte (5 closed, non-unioned shells)
    - models/experimental/triflex-v30-experimental.stl: generated V30, not physically validated
    - cura/TriFlex_Ender3S1_TPU95A_V29_Validated.curaprofile: extracted from the validated V29 G-code; only the display name changed
    - cura/legacy/: original profile kept as a source artifact
    - assets/triflex-v29-render.png: V29 hero render
    - PRINTING.md: validated V29 print used adhesion_type = none (no brim); brim is an optional adhesion aid only
    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
    [triflex-v29.stl, triflex-v30-experimental.stl]
2026-10-05 Promote V30 to stable baseline
    [triflex-v30.stl]
2026-10-14 Add V32-V34 generated experimentals and parametric variant builder
    - Fix V31 arm grooves and record its first print (visual check only)
    - V32: arms 3.29 -> 3.00 mm with a 2.5 mm blend at root and neck
    - V33/V34: 3.0 mm blend, arms 3.00 / 2.80 mm (designer-built, not printed)
    - cad/build.py + cad/variants/*.toml: reproducible variant builds,
    PROTECTED revisions, bounds and watertightness checks
    - cad/gui.py and "TriFlex Builder.command" launcher
    - generate_triflex: sparse_root fallback when the membrane root pinches
    - compare_sections: take membrane positions from the profile
2026-10-17 Add MiniFlex M04 rim-side cylinder trigger family.
    Introduce a separate Ø20 × H16 experimental product for short rim-mounted piezo envelopes, with generator, M01–M04 STLs, physical photos, and test notes. M04 keeps a continuous thick base with an underside cable groove after pad press testing.
2026-10-18 Point electronics work at the sibling TriSense repo.
    Keep triflex-cone mechanical-only; link TriSense for piezo→ESP32→MIDI development.
